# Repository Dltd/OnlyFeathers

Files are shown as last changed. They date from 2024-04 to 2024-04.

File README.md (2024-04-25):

# OnlyFeathers
A ESP32-Cam birdhouse camera project
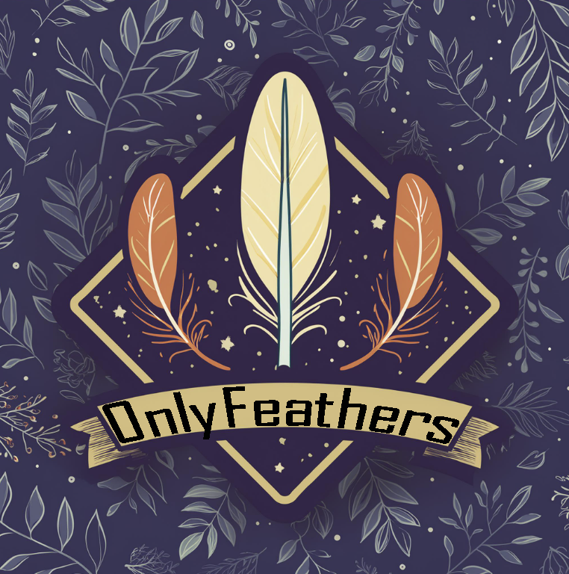
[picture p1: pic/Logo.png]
OnlyfeathersLogo


To learn some more about esp32 I wanted to setup a little birdnest cam.
I added [an external antenna](/Antenna.md) for better WiFi coverage as well.

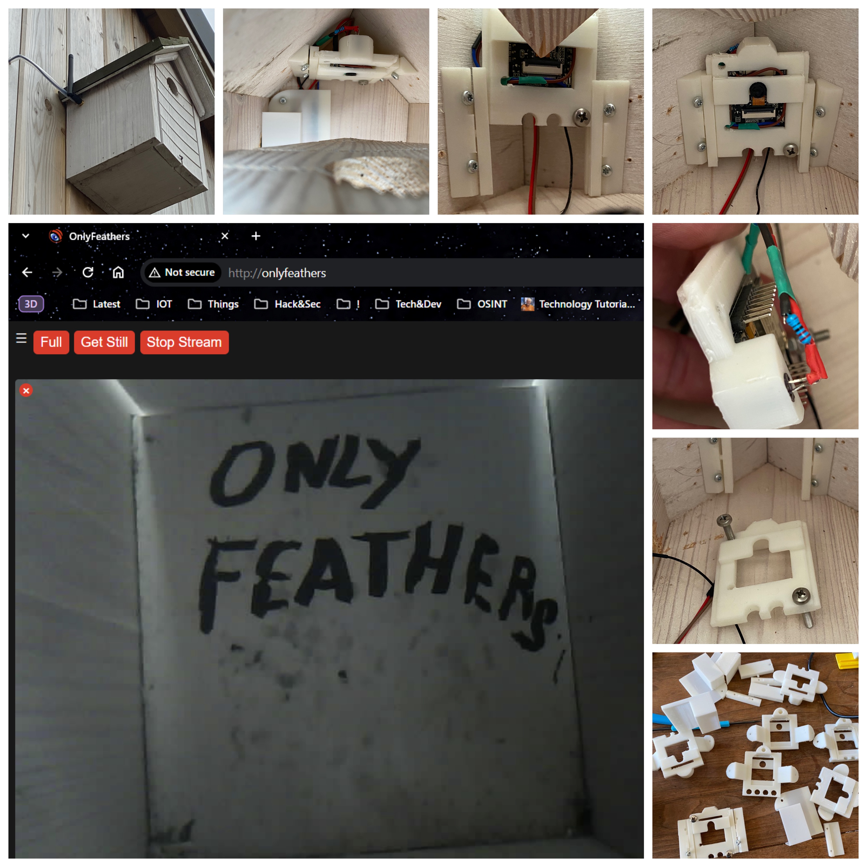
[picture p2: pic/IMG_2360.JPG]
ProjectCollagePicture


I used an esp32-cam and [designed a mount](/ESP32-CAM%20custom%20mount.md) for it that also acts as a infrared light diffuser to light the birdhouse for pictures or video's.

As it appeared, it became already popular on the first day by a returning Great Tit.
You can see it inspecting the cabling and protection in place.
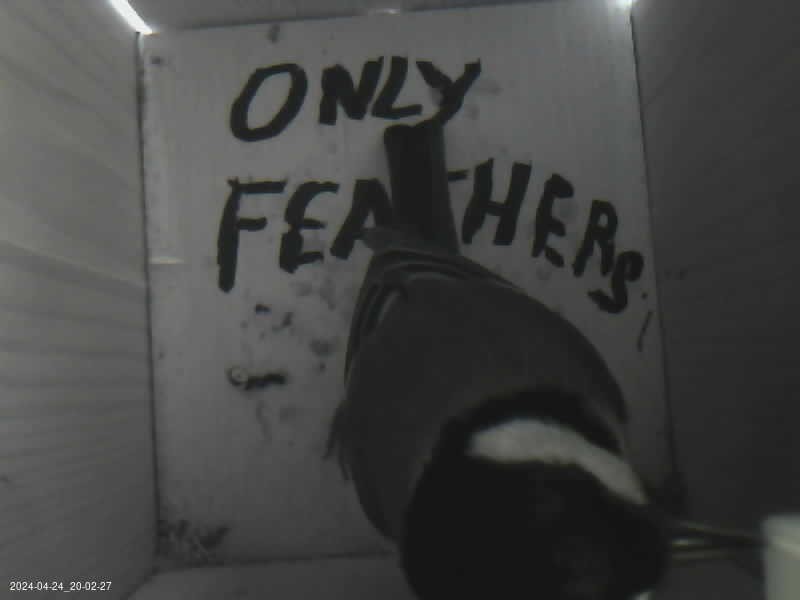
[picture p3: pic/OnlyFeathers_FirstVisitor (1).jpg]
Visitor


For the esp32-cam I used the program [here](https://github.com/easytarget/esp32-cam-webserver/tree/master) which is an improved version of the default example program for esp32-cam webserver.
It works great and is better compared to the example program.

I used a [bright 940nm IR LED](/IR%20LED.md), which I connected to the original SMD flash LED that comes with the board. It was not hard to pry off the led and use a soldering iron and desolder thread to make it nice and clean again.

# finding it in several networks
I set it up to update the ip to a webserver that will receive the private IP address.
It was added because I configured multiple SSID's as redundancy which have their own subnets, this way I can always find it, regardless of the network it has connected to.

If it does not connect to WiFi, the first SSID set in the myconfig.h file will be setup as an accesspoint on the cam.

Change this codesnippet to make it update the IP on a webserver when it has internet connectivity.
```c++
// If we have connected, inform user
        if (WiFi.status() == WL_CONNECTED) {
            Serial.println("Client connection succeeded");
            accesspoint = false;
            // Note IP details
            ip = WiFi.localIP();
            net = WiFi.subnetMask();
            gw = WiFi.gatewayIP();
            Serial.printf("IP address: %d.%d.%d.%d\r\n",ip[0],ip[1],ip[2],ip[3]);
            Serial.printf("Netmask   : %d.%d.%d.%d\r\n",net[0],net[1],net[2],net[3]);
            Serial.printf("Gateway   : %d.%d.%d.%d\r\n",gw[0],gw[1],gw[2],gw[3]);
            calcURLs();
            // Flash the LED to show we are connected
            //for (int i = 0; i < 5; i++) {
            //    flashLED(50);
            //    delay(150);

            // log IP 
            ip = WiFi.localIP();

            String url = "https://YOURWEBSERVER/updateIPhere.php"; // Replace with your actual URL
            String postData = "ip=" + ip.toString(); // Adjust the parameter name as needed
            
            HTTPClient http;
            http.begin(url);
            http.addHeader("Content-Type", "application/x-www-form-urlencoded");
            int httpResponseCode = http.POST(postData);
            if (httpResponseCode == HTTP_CODE_OK) {
                Serial.println("IP address sent successfully");
            } else {
                Serial.printf("Error sending IP address (HTTP code %d)\n", httpResponseCode);
            }

           }
        else {
            Serial.println("Client connection Failed");
            WiFi.disconnect();   // (resets the WiFi scan)
        }
    }
```

You will need some php similar to this to receive the data:

```php
<?php
// thisistheipofthecam.php

// Check if the request method is POST
if ($_SERVER["REQUEST_METHOD"] === "POST") {
    // Retrieve the raw POST data (including all parameters)
    $rawData = file_get_contents("php://input");

    // Parse the raw data into an associative array
    parse_str($rawData, $postData);

    // Extract the relevant values (ip and timestamp)
    $ip = $postData["ip"];
    $timestamp = $postData["timestamp"];

    // Log the extracted data (you can customize the log file path)
    $logFilePath = "esp32-cam_IP.log";
    file_put_contents($logFilePath, "$timestamp $ip\n", FILE_APPEND);

    // Respond with a success message
    echo "Received data successfully";
} else {
    // Respond with an error message if the request method is not POST
    http_response_code(400); // Bad Request
    echo "Invalid request method";
}
?>
```
After it was put back on the shed, it had [a new inhabitant the next day](/First%20Visitor.md)!
Which makes it all worth the effort of course. 

A Raspberry Pi is used to take pictures every 20 seconds, which can be converted to a timelapse video.
For nightvision, it will turn on the LED and let the camera adjust itself to it for 4 seconds to take a picture and turn off the LED again. The script is scheduled in cron to execute every minute

I use this script to make it do that:

```bash
#!/usr/bin/bash

# Set the default shell and path for the script.
SHELL=/bin/sh PATH=/bin:/sbin:/usr/bin:/usr/sbin

# Log the timestamp of execution
echo "$(date) - Executing script" >> /var/log/onlyfeathers.log

# Loop 3 times to perform the actions below.
for ((i=0;i<3;i++)); do

        # Turn on the infrared light before taking the screengrab
        curl "http://onlyfeathers.local/control?var=lamp&val=95"
        # Sleep to let the camera adjust itself
        sleep 4
        # Download an image from the new host URL and save it with a timestamped filename.
        wget http://onlyfeathers.local/capture -O "/home/onlyfeathers/timelapsepics/only_feathers_$(date +%Y-%m-%d_%H-%M-%S).jpg"
        # Turn off the infrared light again
        sleep 1
        curl "http://onlyfeathers.local/control?var=lamp&val=0"

        # Find the most recently downloaded image.
        latest=$(ls /home/onlyfeathers/timelapsepics/only_feathers_*.jpg -rt1 | tail -1)
        # Extract the filename without the extension for watermarking.
        Watermarktext=$(basename "$latest" .jpg | sed 's/only_feathers_//')

        # Get the size of the latest image.
        ps=$(wc -c <"$latest")
        # Set a minimum size threshold.
        mn=7000

        # If the image is smaller than the threshold, adjust camera settings and retake the image.
        if [ $ps -le $mn ]; then
          curl "http://onlyfeathers.local/control?var=framesize&val=9"
          curl "http://onlyfeathers.local/control?var=raw_gma&val=0"
          curl "http://onlyfeathers.local/control?var=hmirror&val=0"
          curl "http://onlyfeathers.local/control?var=vflip&val=0"
          curl "http://onlyfeathers.local/control?var=dcw&val=0"
          sleep 5.0
          # Retake the image after the settings are adjusted.
          wget http://onlyfeathers.local/capture -O "/home/onlyfeathers/timelapsepics/only_feathers_$(date +%Y-%m-%d_%H-%M-%S).jpg"
          latest=$(ls /home/onlyfeathers/timelapsepics/only_feathers_*.jpg -rt1 | tail -1)
        fi

        # Apply a small watermark text to the image for the timestamp.
        Fontsize=10
        Font="Arial.ttf"
        Fontcolour="white"
        horizontal=$(identify -format "%w" "$latest")
        vertical=$(identify -format "%h" "$latest")
        Textdistancefromleft=10
        Textdistancefrombottom=10
        X=$Textdistancefromleft
        Y=$((vertical - Textdistancefrombottom))
        convert -quality 50 -pointsize $Fontsize -fill $Fontcolour -draw "text $X, $Y '$Watermarktext'" "$latest"  "$latest"

        # Copy the watermarked image to the web directory.
        cp $latest /var/www/html/only_feathers.jpg

        # Wait for 17.6 seconds before the next iteration of the loop.
        sleep 17.6
done
# Exit the script.
exit
```

[Here are some video's](/Video.md) of the building process and [here are some pictures](/Pics.md) as well.

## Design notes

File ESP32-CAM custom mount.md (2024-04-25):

# ESP32-CAM custom mount

It took a few iterations to get to the mount that I used for the project.
I wanted it to be sort of modular so it would be easier to place/remove it during the testing phase, the first version was less ideal to debug or troubleshoot issues.

In the final version I only added an M4 bolt with two nuts on it as a counterweight so that it would keep the camera more focused to the center instead of the back that would be more visible if it would not be aimed properly, hence the many try out prints to make it work.

The final version

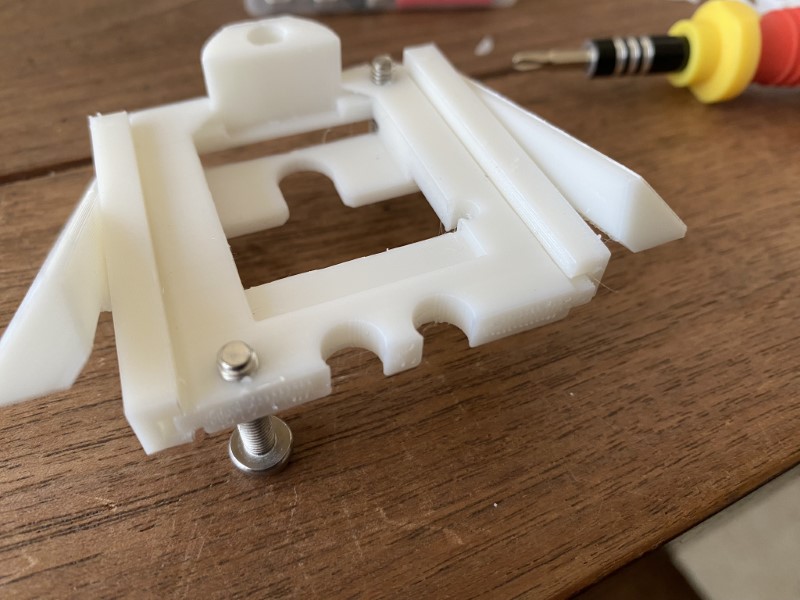
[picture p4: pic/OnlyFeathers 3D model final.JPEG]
The final version


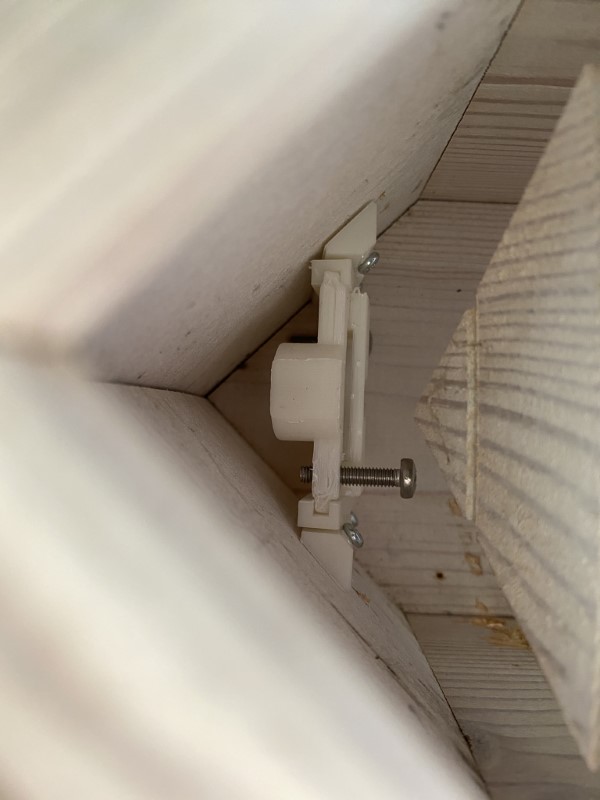
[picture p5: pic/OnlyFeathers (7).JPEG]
Final


Meet the prototype family

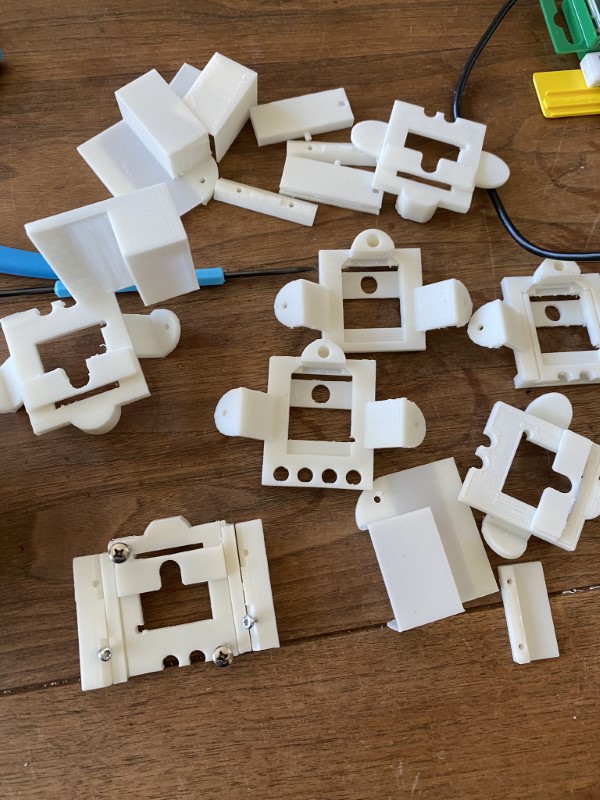
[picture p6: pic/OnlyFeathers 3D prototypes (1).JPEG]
Meet the prototype family


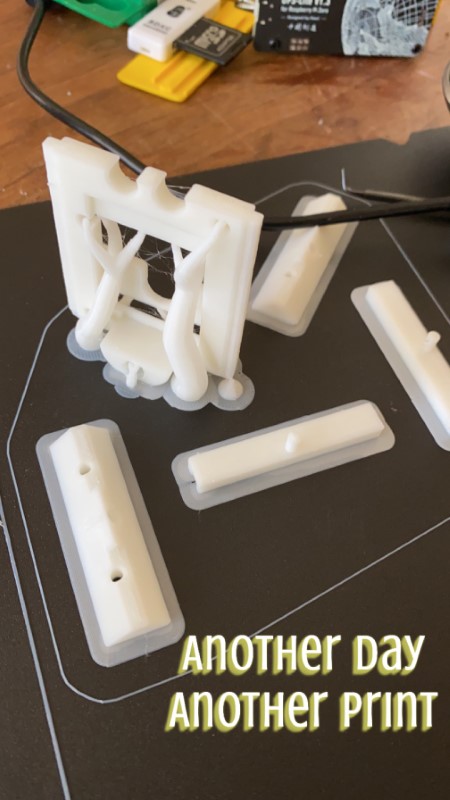
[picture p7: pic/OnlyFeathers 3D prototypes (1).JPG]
 

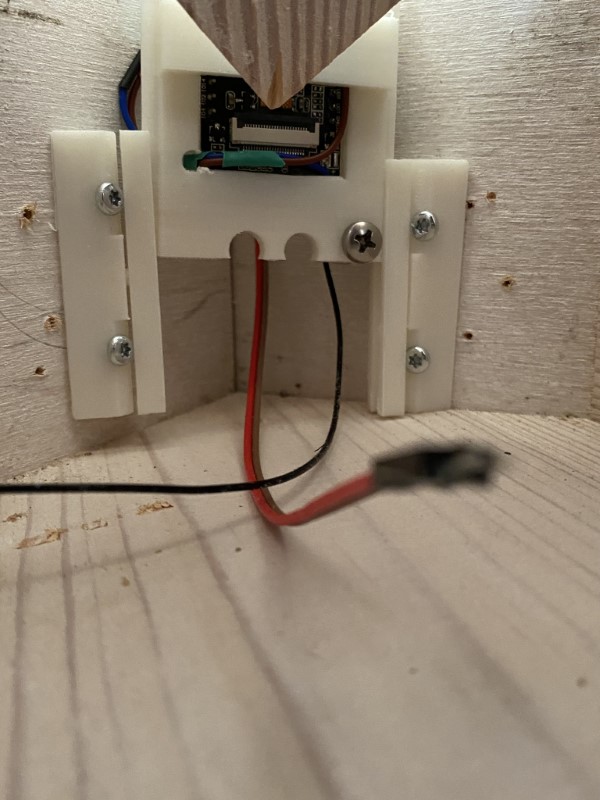
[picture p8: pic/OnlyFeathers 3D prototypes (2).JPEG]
 

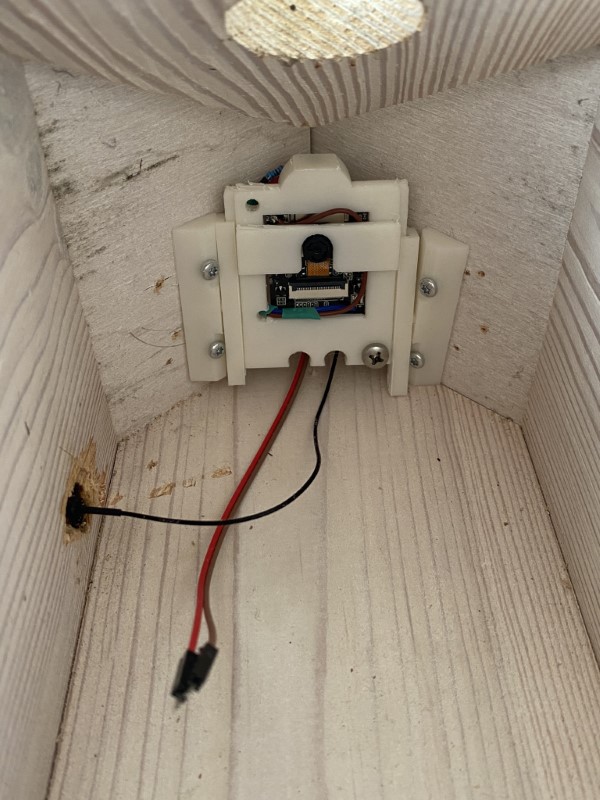
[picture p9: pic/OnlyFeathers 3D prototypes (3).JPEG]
 

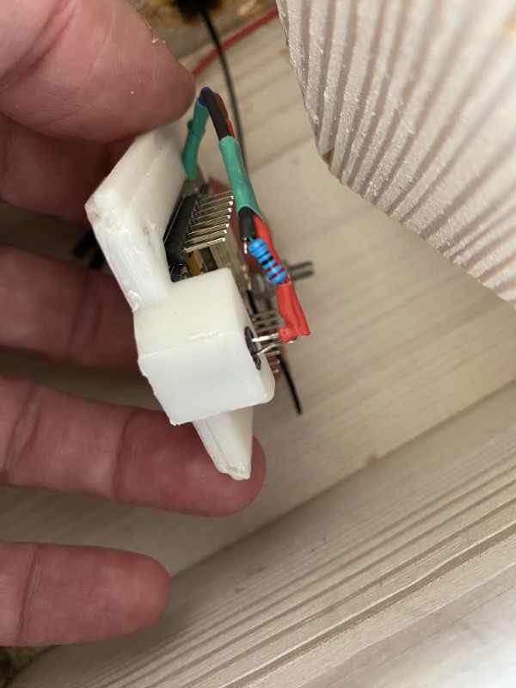
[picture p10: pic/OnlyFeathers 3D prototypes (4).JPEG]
 

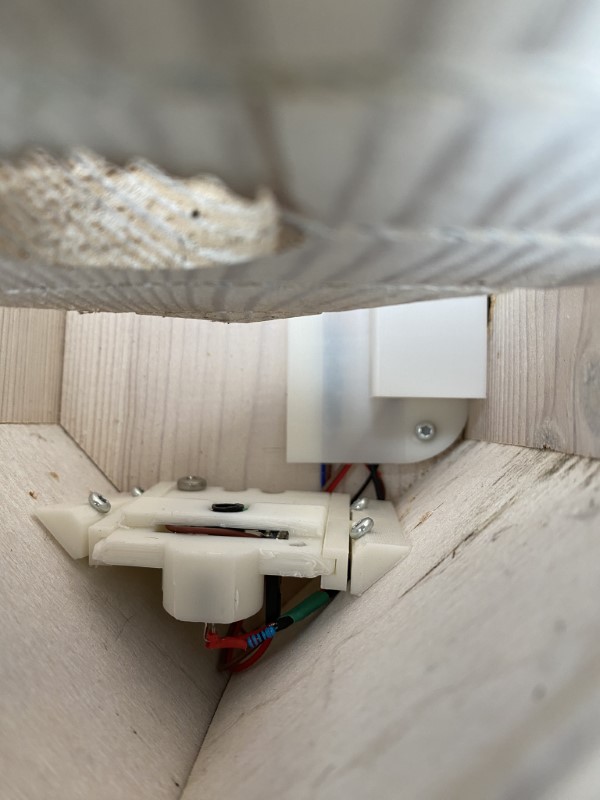
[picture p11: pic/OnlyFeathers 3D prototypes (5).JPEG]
 

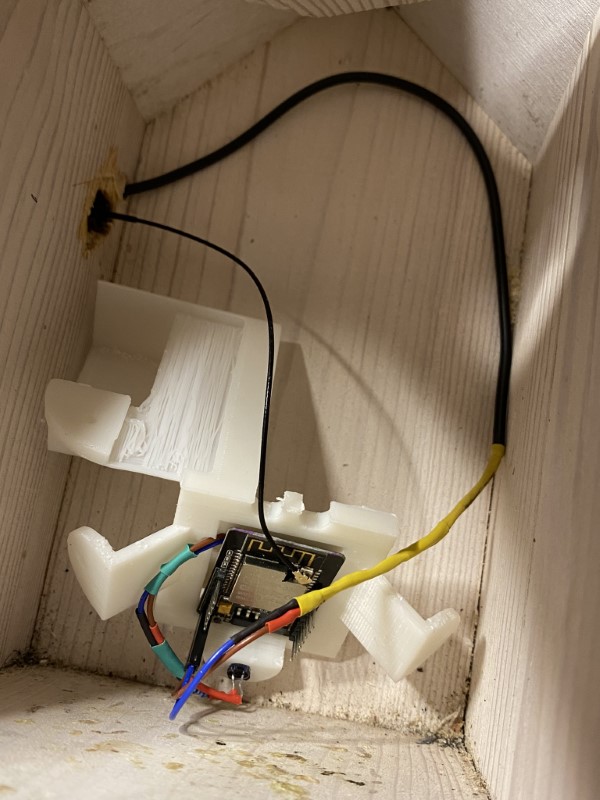
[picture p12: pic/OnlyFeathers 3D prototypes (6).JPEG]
 

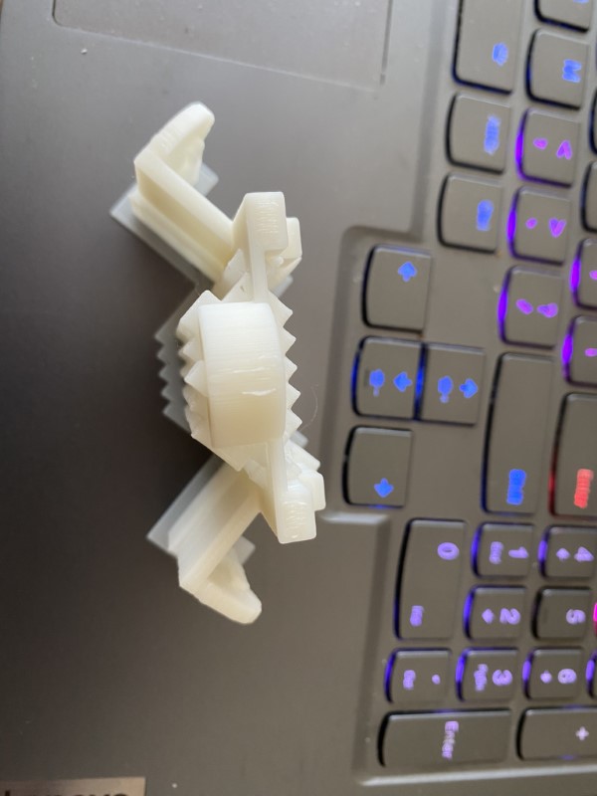
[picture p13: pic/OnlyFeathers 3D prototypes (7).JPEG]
 

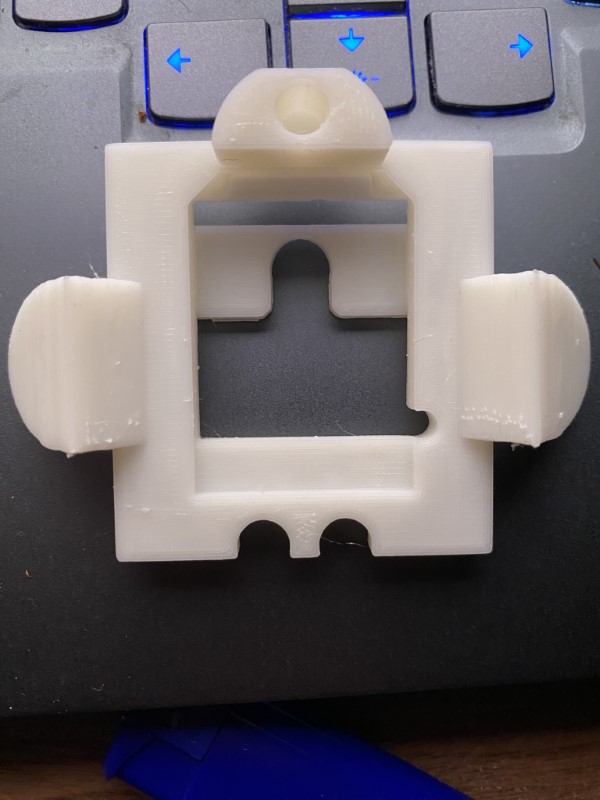
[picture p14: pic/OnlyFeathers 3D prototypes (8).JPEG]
 

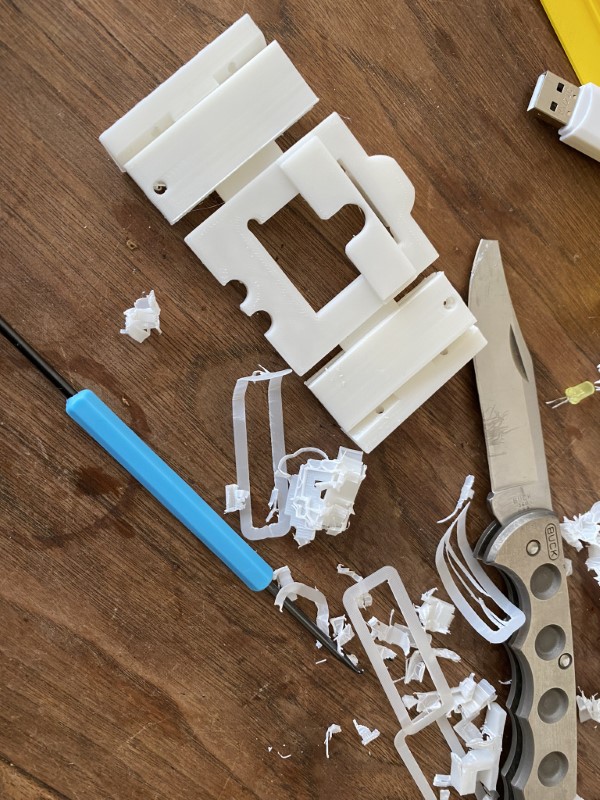
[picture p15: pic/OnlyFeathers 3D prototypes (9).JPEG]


# ESP32-cam custom mount 3D files 
[ESP32-cam Mount](3D-files/OnlyFeathers_Mount420_finalv1.stl)

[Mount Holder](3D-files/OnlyFeathers_Mount420_holder_finalv1.stl)

[Roof attachment for holder with mount](3D-files/OnlyFeathers_Mount420_roofpart_finalv1.stl)

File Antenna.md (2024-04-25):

# External Antenna

To improve network coverage, I added an external antenna.

This seemed not sufficient in the end so I ended up with a wifi mesh AP in the shed as the signal is too low for esp32-cam to have a reliable connection through the glass and walls.

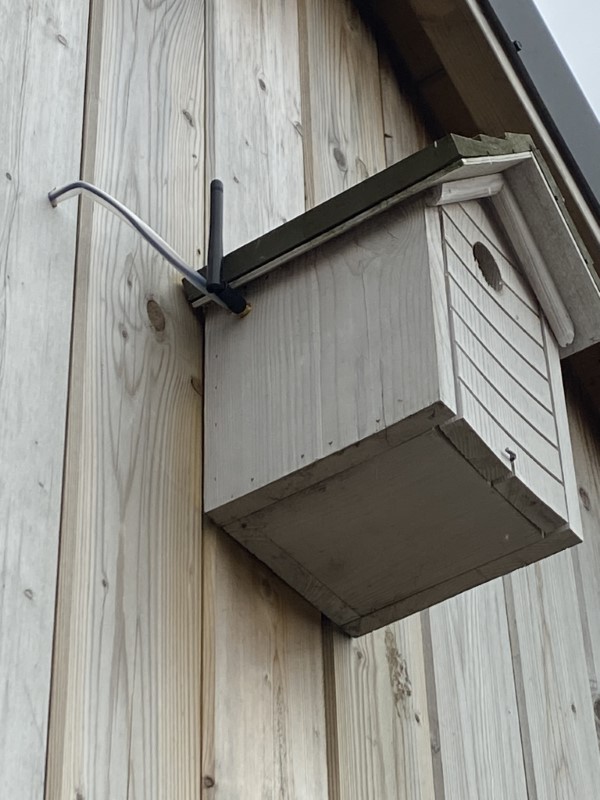
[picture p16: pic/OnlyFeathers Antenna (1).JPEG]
Birdhouse with antenna and powerchord
 

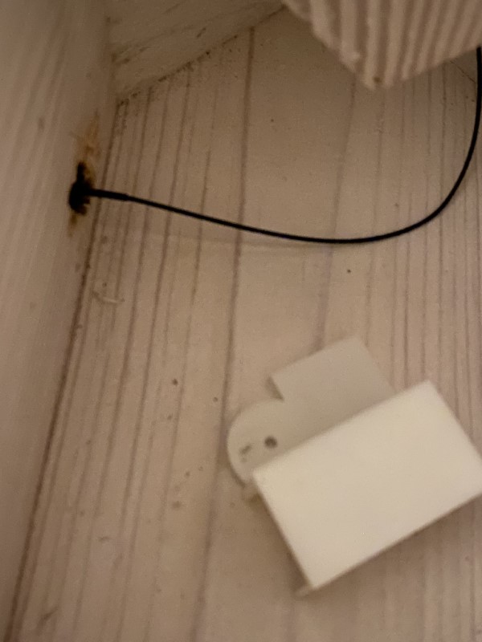
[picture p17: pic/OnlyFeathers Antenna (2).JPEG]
Cable inside
 

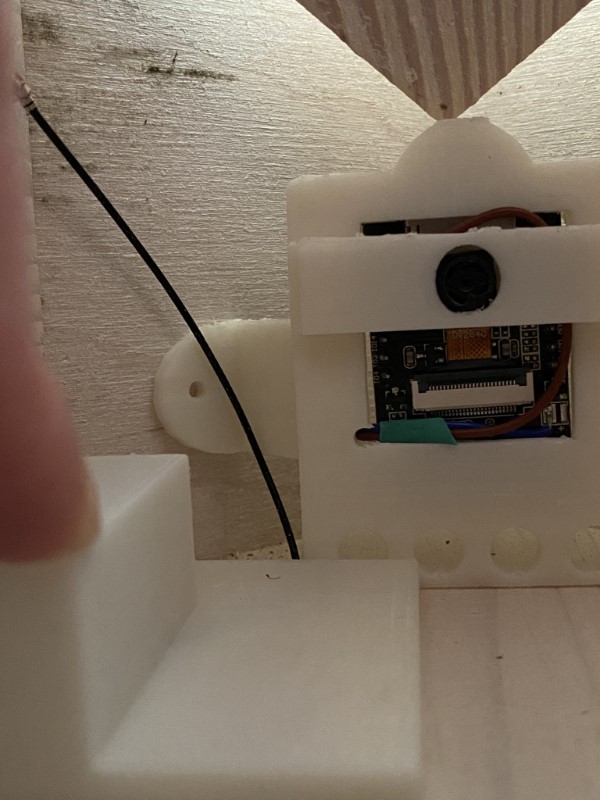
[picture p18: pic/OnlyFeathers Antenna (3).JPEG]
Cable and mount+cable protection
 

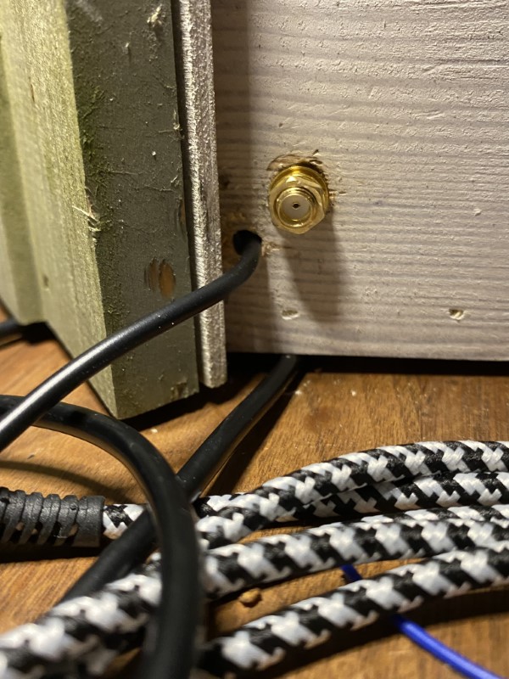
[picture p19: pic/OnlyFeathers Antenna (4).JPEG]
Antenna connector outside
 

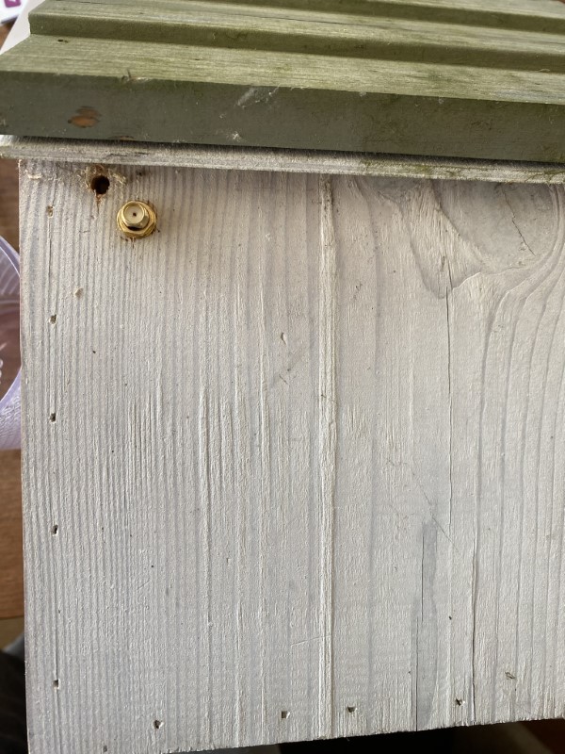
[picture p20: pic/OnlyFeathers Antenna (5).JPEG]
Antenna connector outside
 

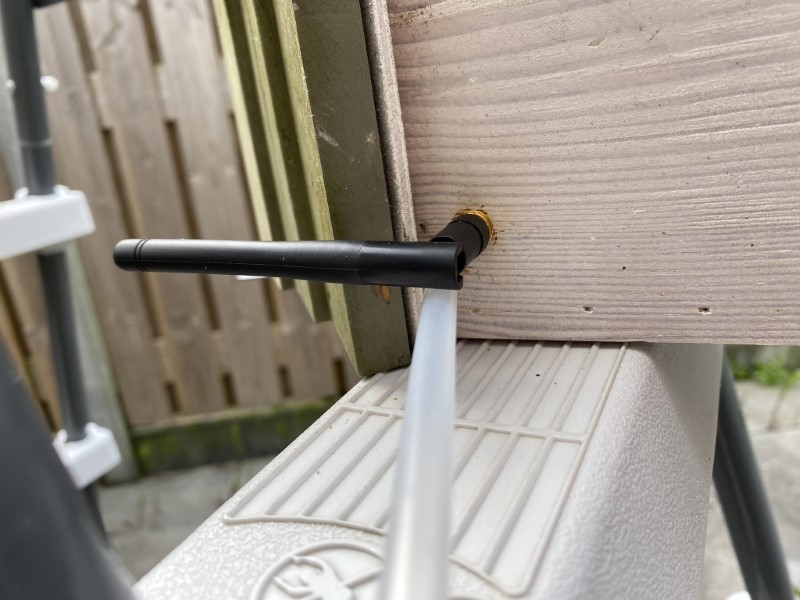
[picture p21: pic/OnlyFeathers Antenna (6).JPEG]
Antenna connector outside
 

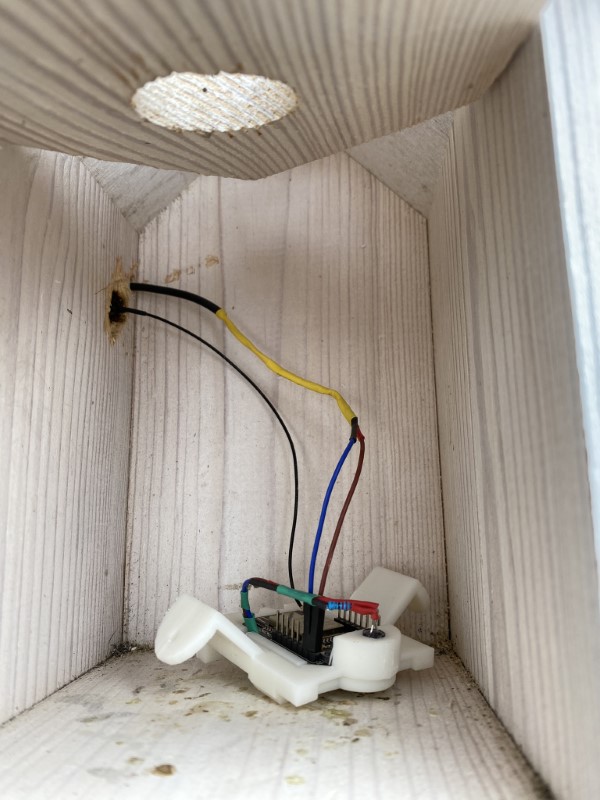
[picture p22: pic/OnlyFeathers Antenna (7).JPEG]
Antenna and power cable
 

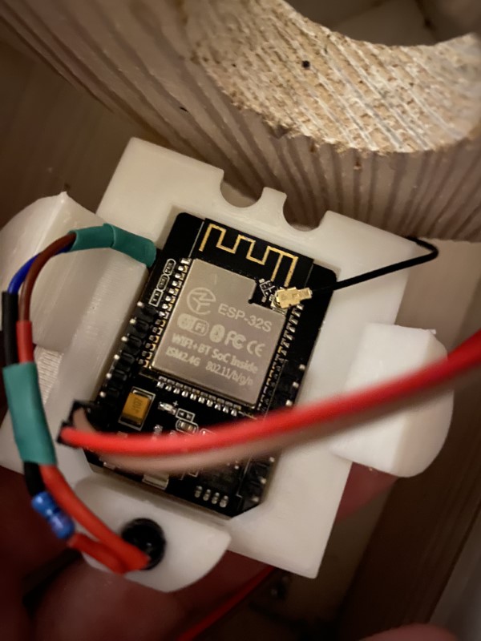
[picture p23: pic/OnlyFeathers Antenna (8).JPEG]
Antenna, power and led connected


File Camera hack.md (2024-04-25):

# Camera hack for the IR LED - removing the IR filter

Since I did not want to wait for another camera to arrive, I removed the IR filter of the camera lens.
This way it would become suitable for the use of IR LED's for night images.

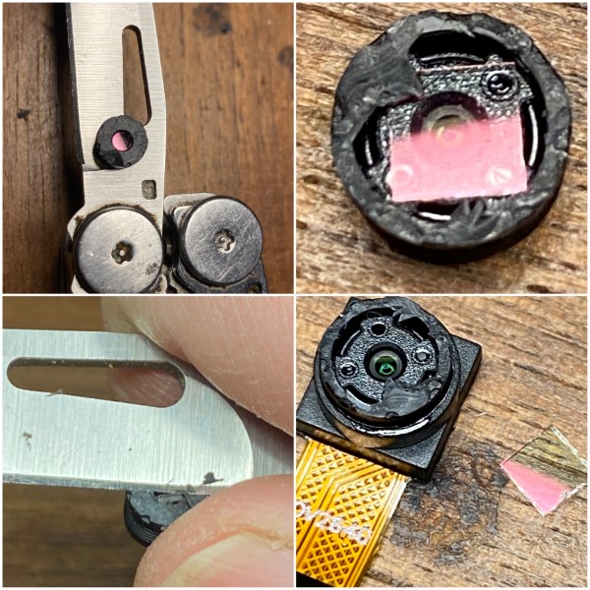
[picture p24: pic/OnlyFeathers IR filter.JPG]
Small collage


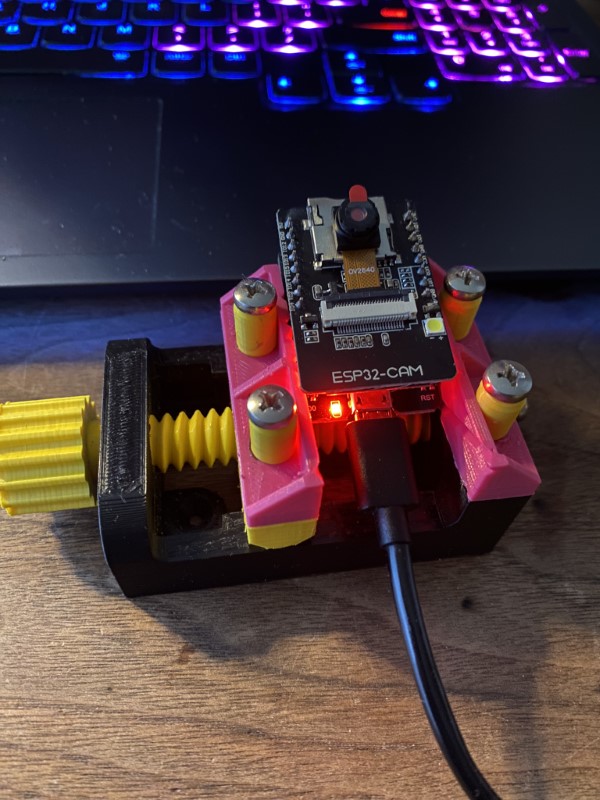
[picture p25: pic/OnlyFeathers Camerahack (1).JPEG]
 

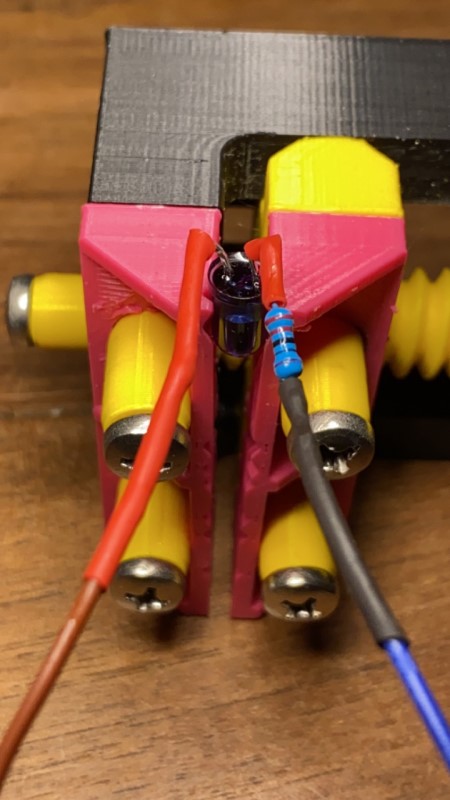
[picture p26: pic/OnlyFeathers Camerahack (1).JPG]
 

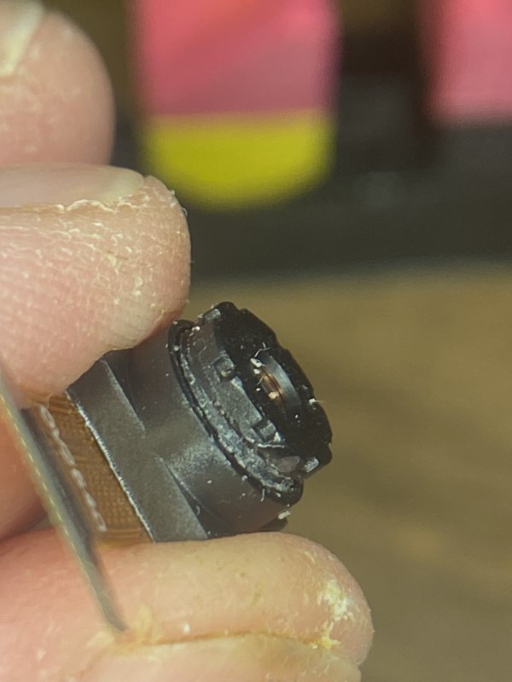
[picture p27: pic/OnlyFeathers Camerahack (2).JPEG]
 

Camhack 

Camhack 

Camhack 

Camhack 

Camhack 

Camhack 

Camhack

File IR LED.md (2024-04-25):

# IR LED

IR LED soldered to the Flash LED

With a potentiometer I tested which brightness I wanted it to be on, I also measured it to not draw too much current.
Breadboard setup with pot.meter



Resistance is Futile 

ESP32cam with flashled 

Flashled removal 

Flashled removal 

Flashled removed 

Ground wire soldered

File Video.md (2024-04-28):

Full playlist [here](https://www.youtube.com/playlist?list=PLgzRFpQ9xYKAYCfvw1oh3P7lQ6fxIQnga)

Links to seperate vids here:

[](https://www.youtube.com/watch?v=8ftNLXxl2lA)

[](https://www.youtube.com/watch?v=cGnTstsCY98)

[](https://www.youtube.com/watch?v=UGqaUv2kMJE)

[](https://www.youtube.com/watch?v=0XO5rdPtHgI)

[](https://www.youtube.com/watch?v=2TawlGHPGfo)

[](https://www.youtube.com/watch?v=ixfo1hJ01aQ)

[](https://www.youtube.com/watch?v=VH_afHw79cI)

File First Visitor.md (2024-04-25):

# First Visitor making itself comfortable to take a long nap.

Great Tit 

Great Tit 

Great Tit

Great Tit 

Great Tit 

Great Tit 

Great Tit 

Great Tit

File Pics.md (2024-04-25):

# Some more Pics

 

 

 

 

 

 

 

 



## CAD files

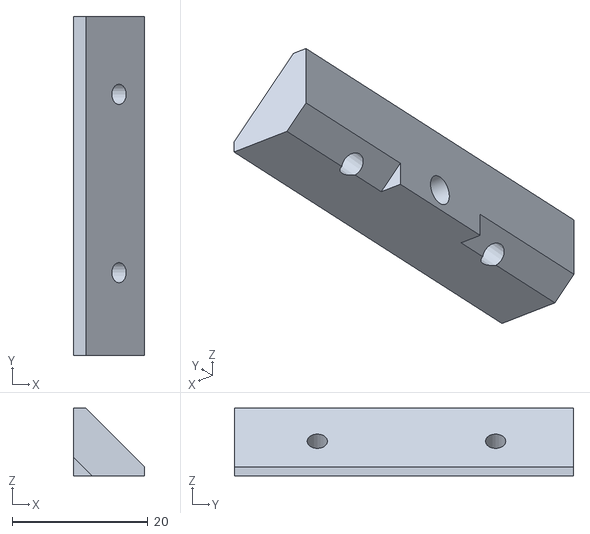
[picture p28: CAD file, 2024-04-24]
3D-files/OnlyFeathers_Mount420_roofpart_finalv1.stl
10.5 x 50.0 x 10.0

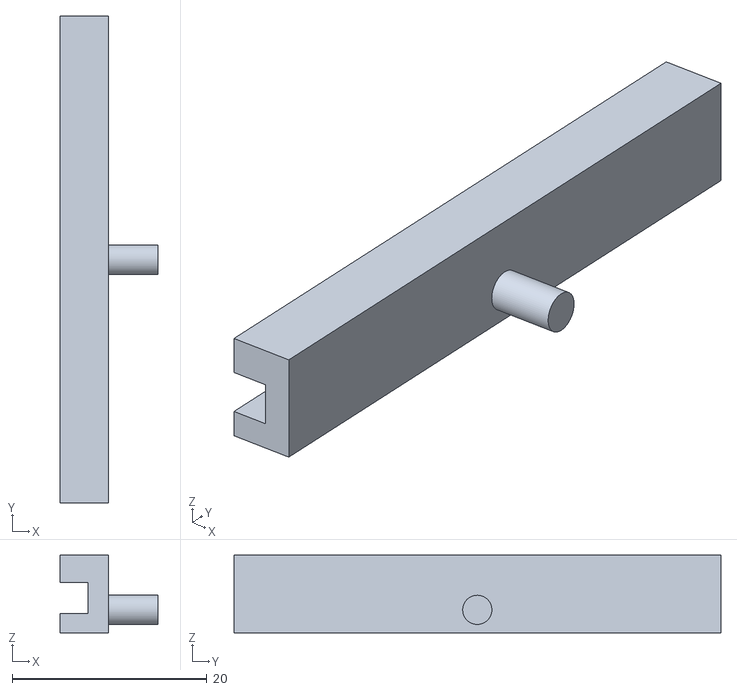
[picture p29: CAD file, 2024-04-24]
3D-files/OnlyFeathers_Mount420_holder_finalv1.stl
10.1 x 50.0 x 8.00

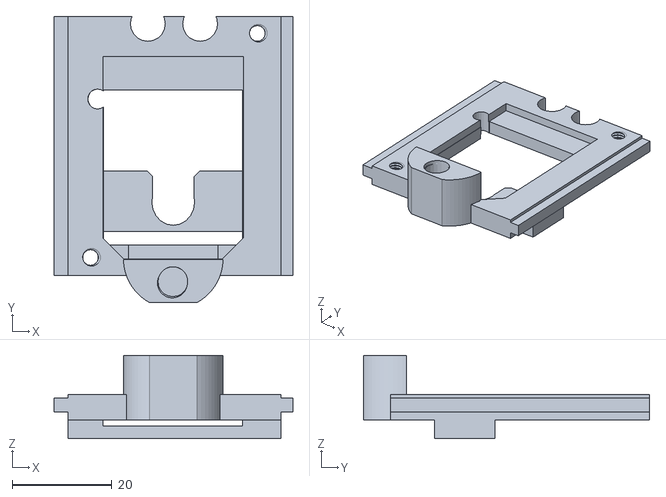
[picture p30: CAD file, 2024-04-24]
3D-files/OnlyFeathers_Mount420_finalv1.stl
48.0 x 57.5 x 16.7
